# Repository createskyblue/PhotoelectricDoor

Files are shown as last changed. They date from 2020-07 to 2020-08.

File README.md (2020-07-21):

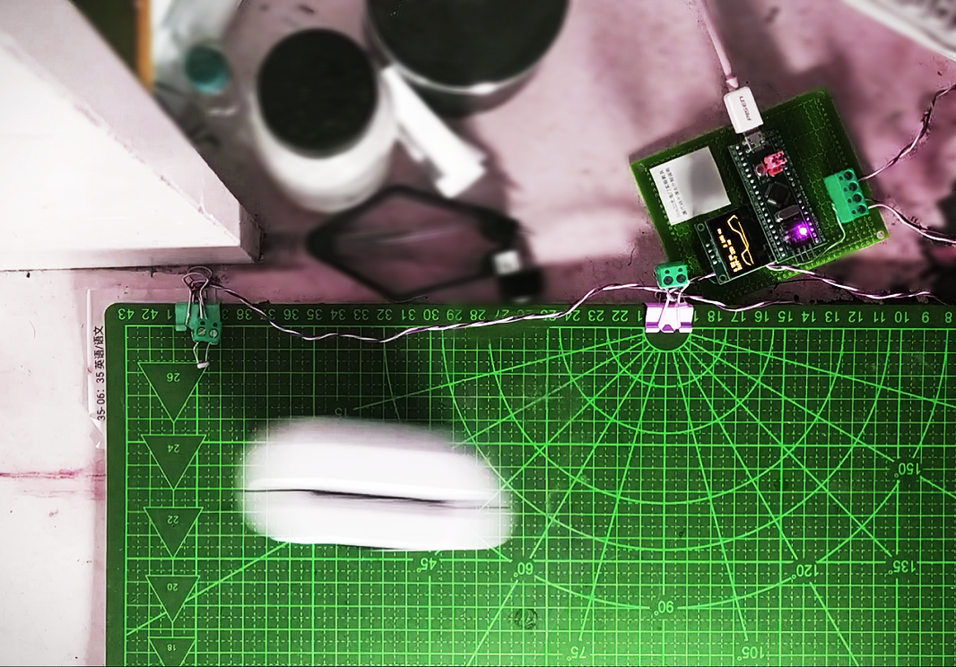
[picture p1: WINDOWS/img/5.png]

在这次实验，我们使用STM32单片机和由两个光敏电阻以及平行光源组组成的A和B两个光电门来计算运动物体的加速度，物体通过两个光敏电阻时会遮挡平行光，此时stm32单片机会记录下两个光敏电阻上的电位变化通过串口通讯把波形上传到计算机以待进一步分析，并且在STM32的OLED显示屏上显示出两个光敏电阻的遮光时间以及通过两个光敏电阻之间的时间差。
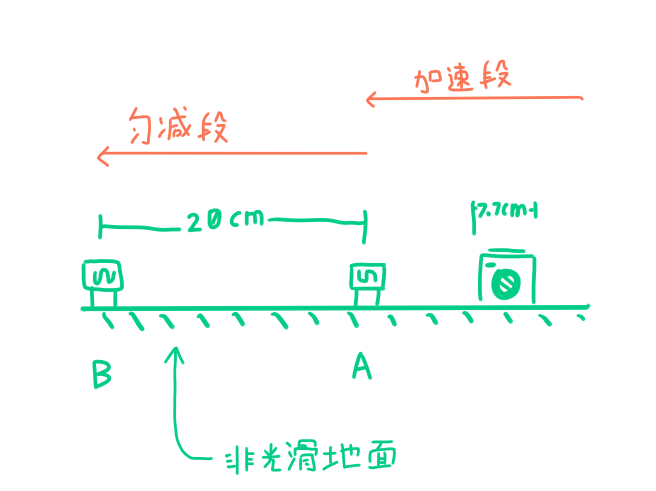
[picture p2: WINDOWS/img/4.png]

上图为为实验具体示意图，现在有一遮光长度为7.7CM的热敏打印机，我们对其进行加速直到打印机进入光电门A，计算机记录下第一个遮光时间t1，待热敏打印机通过光电门B时，计算机会记录下通过离开光电门A后直到进入光电门B的时间差t2，最后热敏打印机离开光电门B，计算机最后记录下第二个遮光时间t3。热敏打印机进入光电门A后受到摩檫力作匀减速运动，利用热敏打印机遮光长度7.7CM组合t1和t3可以计算出通过光电门A、B的速度V1和V2,最后利用时间差t3可以计算出热敏打印机作匀减运动的加速度！
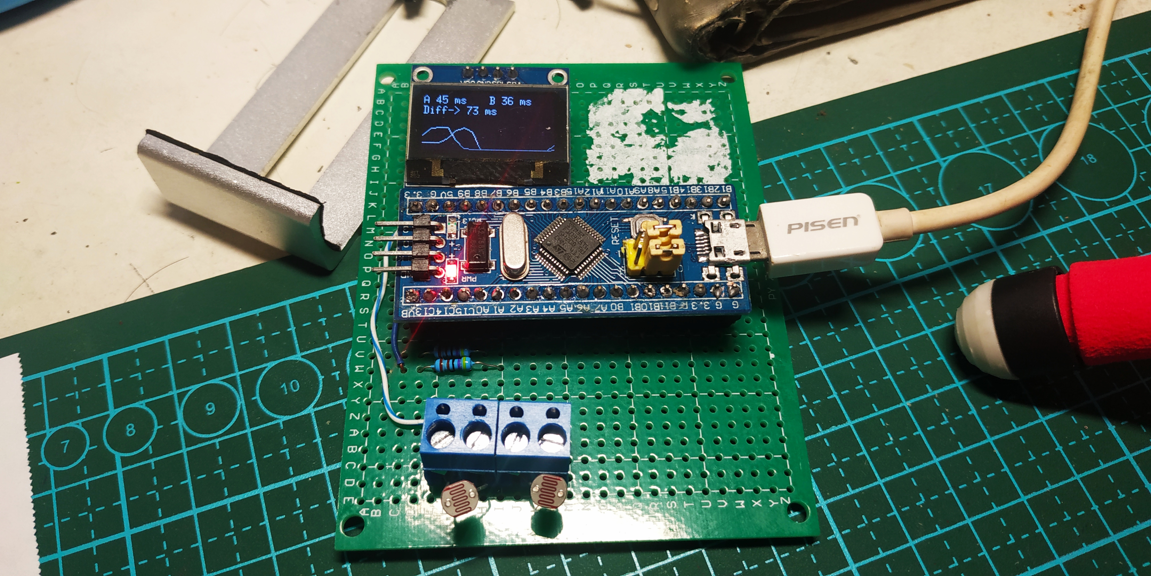
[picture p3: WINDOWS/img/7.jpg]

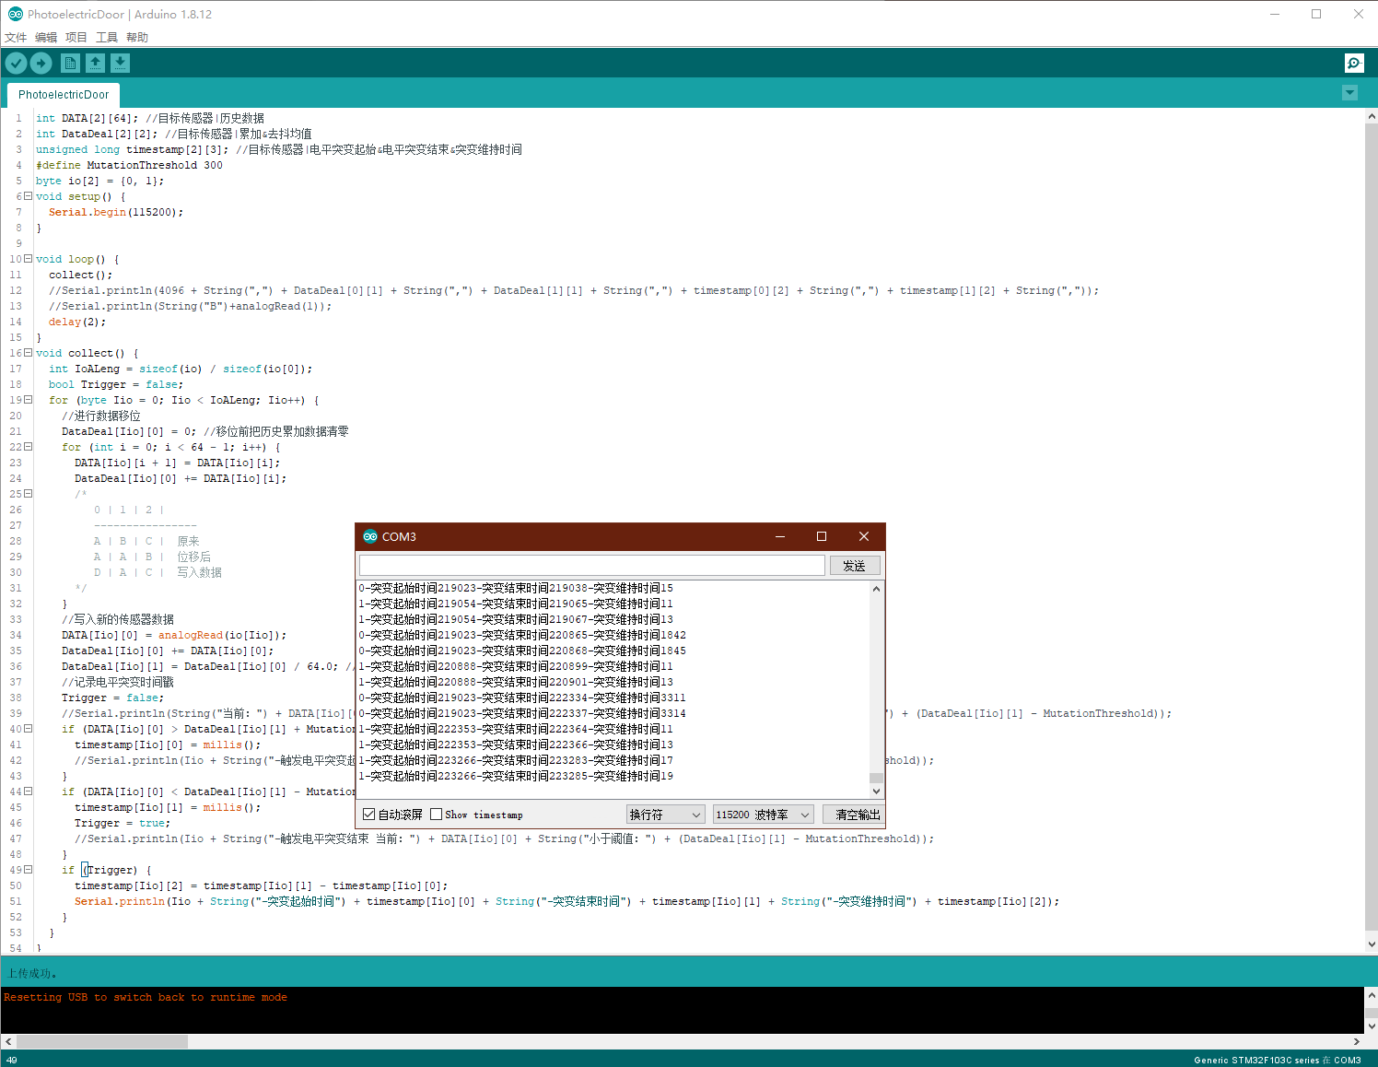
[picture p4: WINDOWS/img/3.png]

为了方便在大屏幕上进行演示，我还制作了上位机软件，根据STM32通过串口通讯上传的波形数据以及处理好的时间数据对加速度进行计算
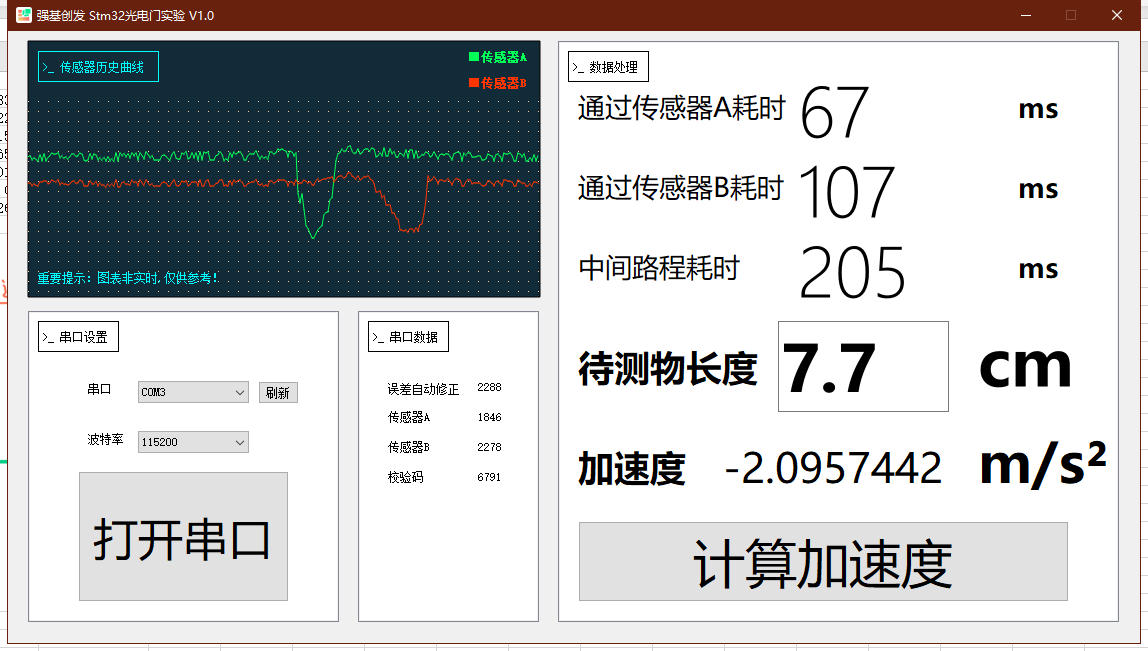
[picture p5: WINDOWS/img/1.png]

我们再重复进行多次实验，去除最高和最低的数据，得出这张加速度表
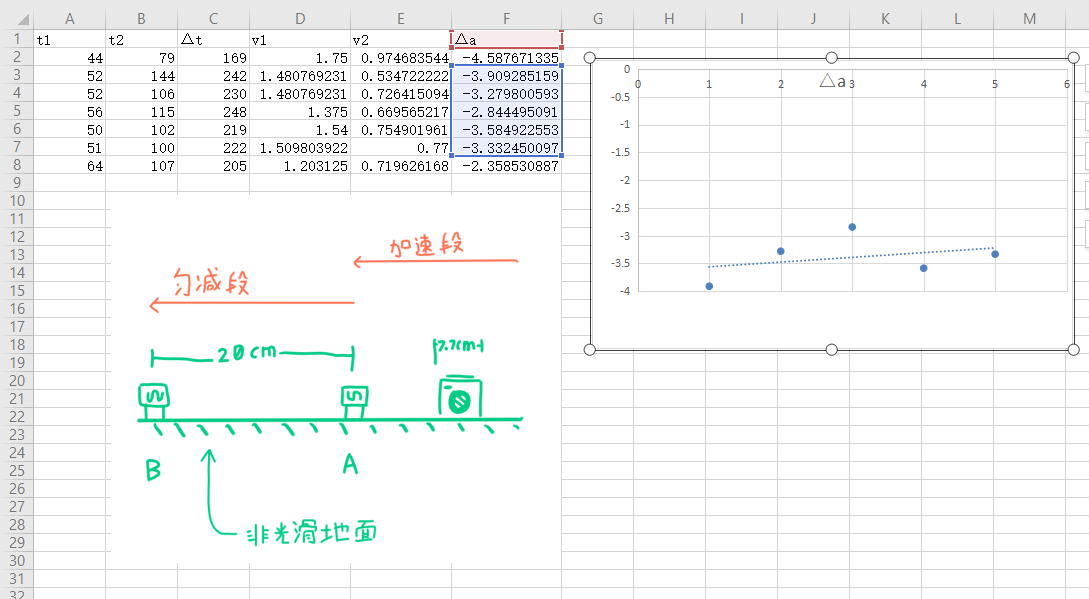
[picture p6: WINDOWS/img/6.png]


# 附录-1
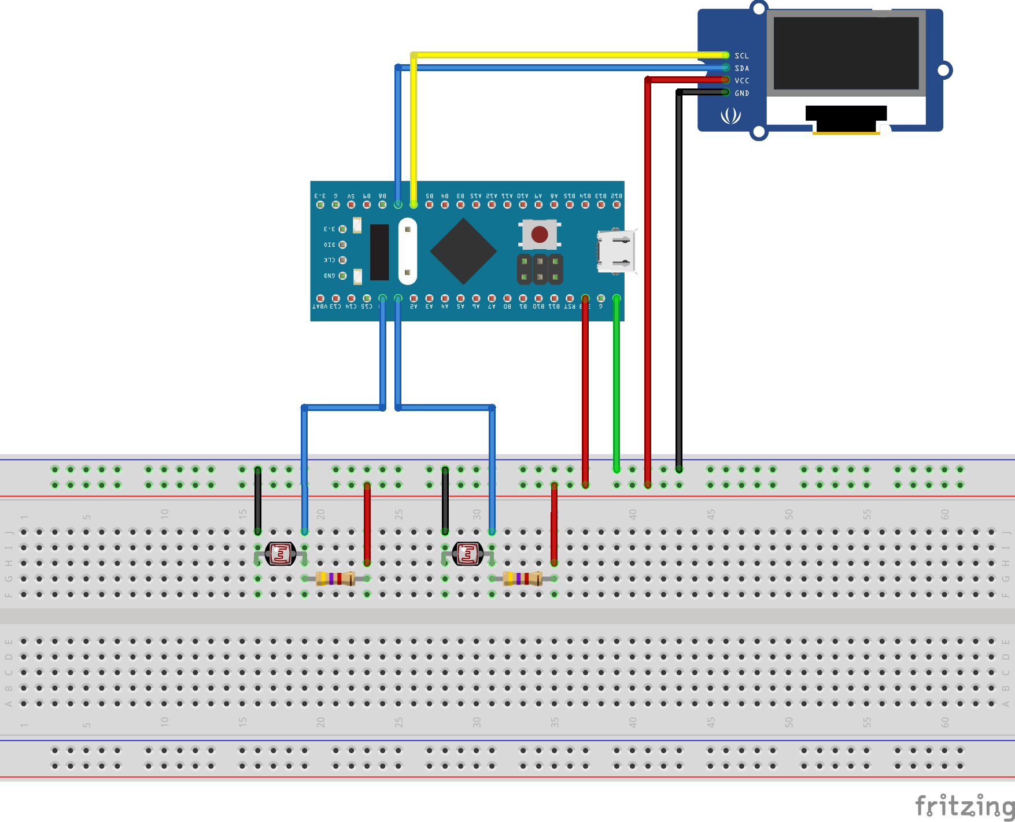
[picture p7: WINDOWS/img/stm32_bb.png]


###### 提示:STM32光电门程序后OLED会显示出启动信息，随后自动进行调光，此时请确保将光敏电阻置于实验环境下，当调光结束后OLED会显示两张启动画面中的一张譬如：

###### 则表明调光程序已自动完成，如果光照条件改变，请务必按下复位按钮重新调光！启动画面结束后随后进入操作界面，并且光电门时有顺序之分的，可以根据附带的接线图所示，光电门A连接到单片机的A0,光电门B连接到单片机的A1。进行试验时确保被测物先通过光电门A再通过光电门B，并且确保两光电门之间保持合适距离，确保收集到准确的实验数据！

# 附录-2
WINDOWS上位机软件所在目录
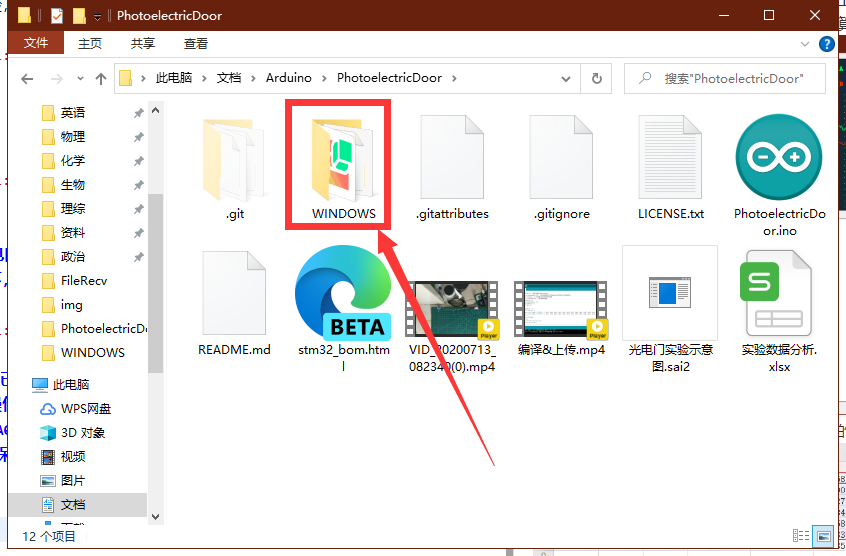
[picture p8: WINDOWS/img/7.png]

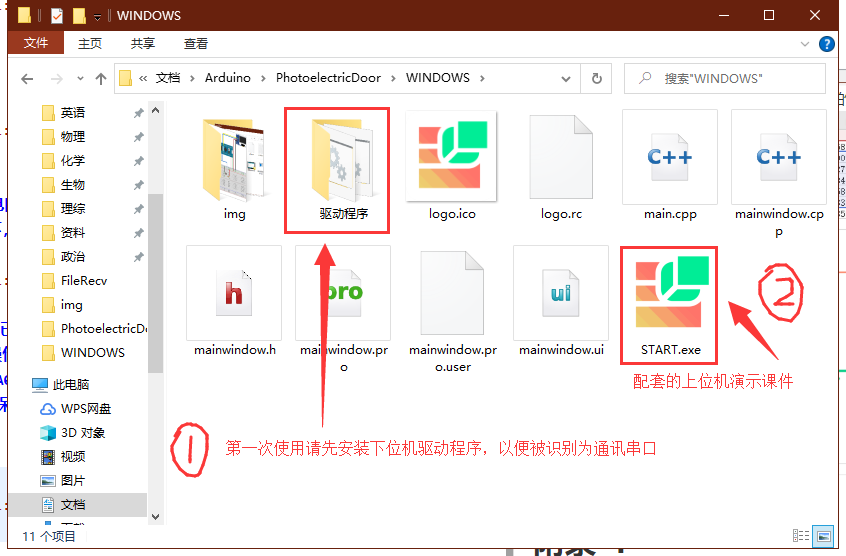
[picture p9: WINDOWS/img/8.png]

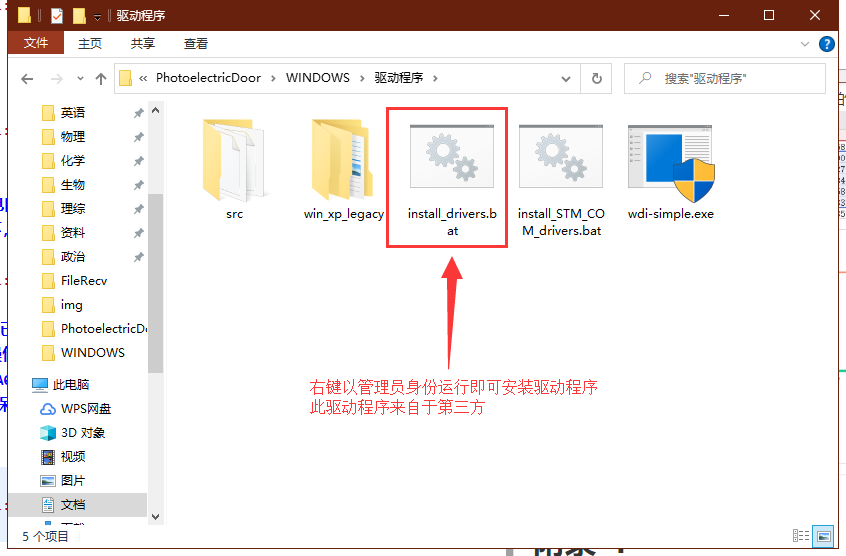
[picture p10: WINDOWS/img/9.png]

上位机软件操作
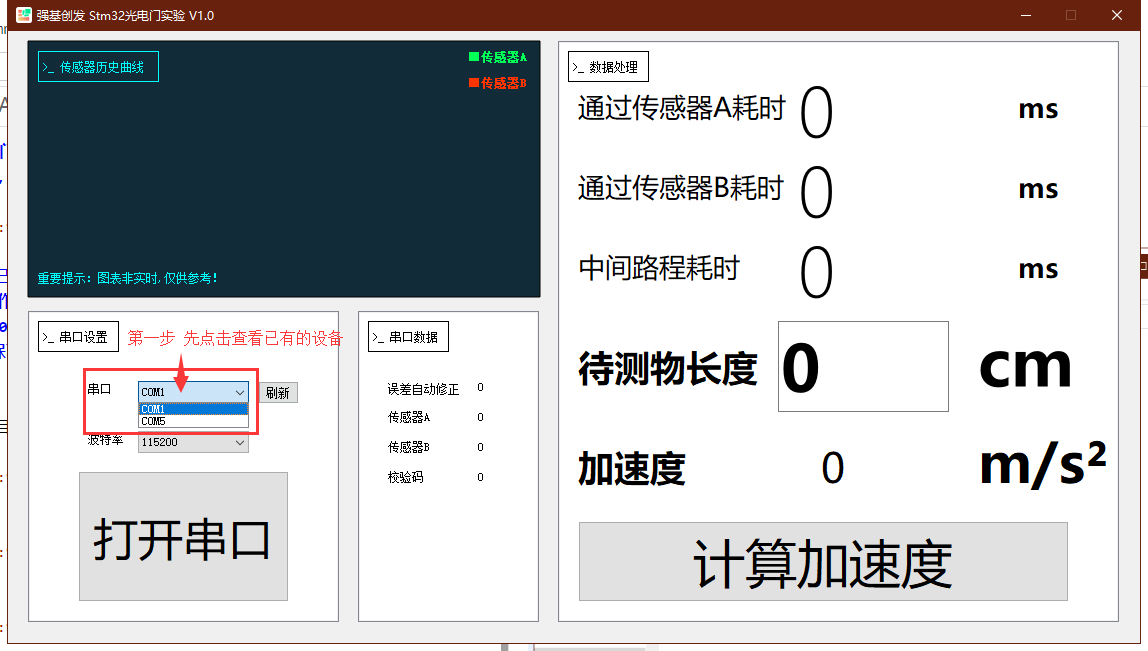
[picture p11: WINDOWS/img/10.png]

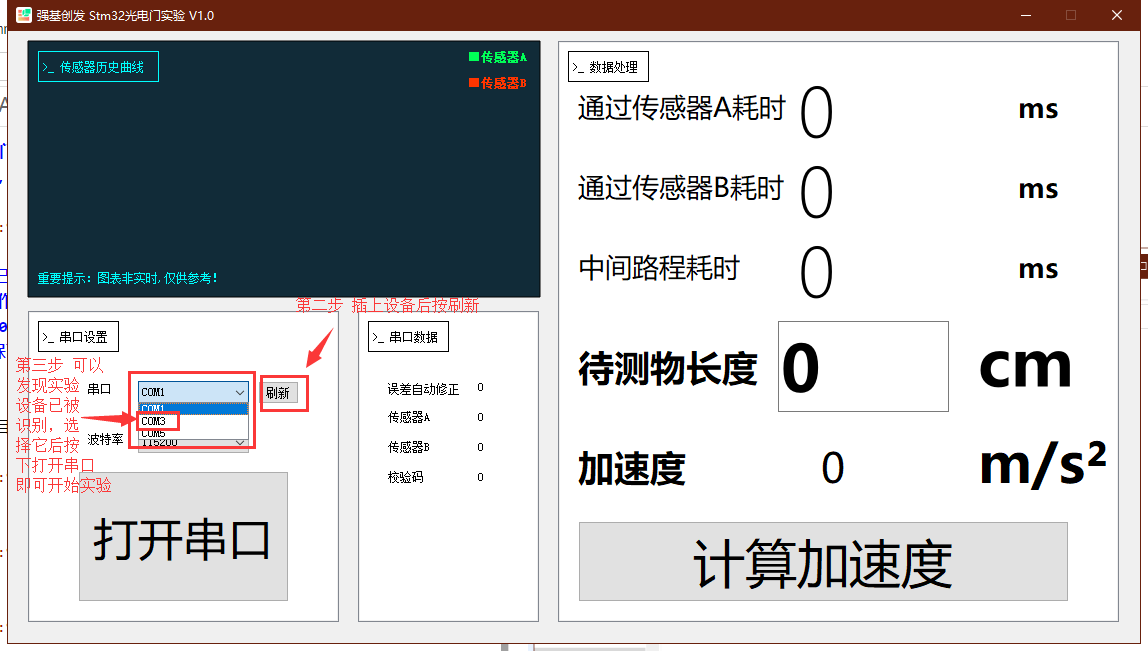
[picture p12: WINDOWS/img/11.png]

望各位老师使用愉快！若遇到问题可以发邮件到createskyblue@outlook.com

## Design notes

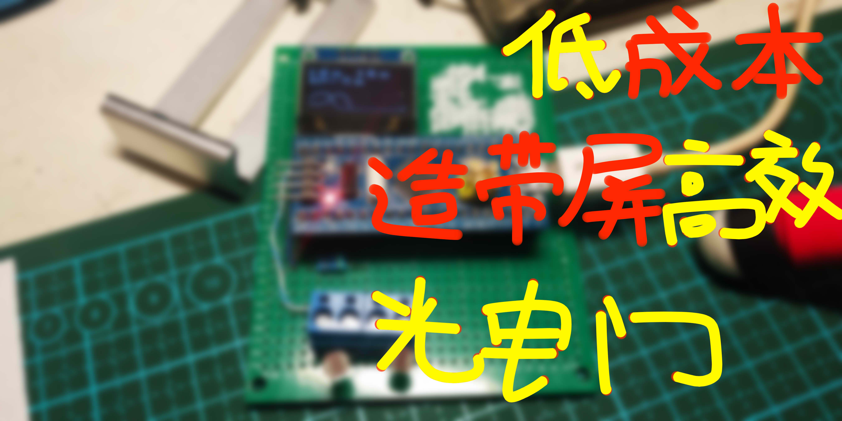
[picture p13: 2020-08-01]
WINDOWS/img/bilibili.jpg

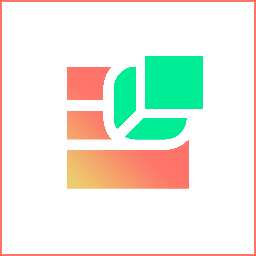
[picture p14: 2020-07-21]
WINDOWS/img/screen.png

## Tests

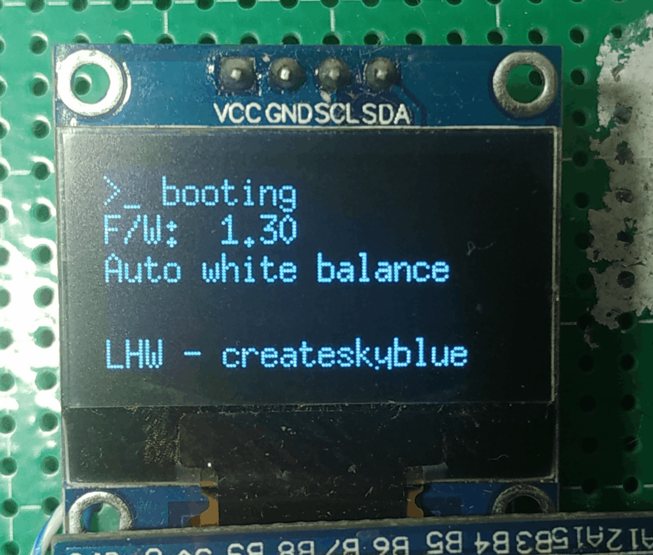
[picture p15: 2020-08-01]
WINDOWS/img/TestMode.gif

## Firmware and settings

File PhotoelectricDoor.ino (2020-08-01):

/*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
  光电门下位机程序版本:
  V2.0
*/
#include <U8g2lib.h>
//#include <SPI.h>
//U8G2_ST7565_JLX12864_F_4W_SW_SPI u8g2(U8G2_R0,19,20,14,22,21);
U8G2_SSD1306_128X64_NONAME_F_HW_I2C u8g2(U8G2_R0, /* clock=*/ PB6, /* data=*/ PB7, /* reset=*/ U8X8_PIN_NONE);
#define TmpDateMax 64
int DATA[2][TmpDateMax]; //目标传感器|历史数据
bool TriggerTimer = false;
bool GUIState = false;
bool State[2] = {1, 1}; //传感器状态
int grap[2][17]; //图形缓冲区
byte GrapX;
int DataDeal[2][2]; //目标传感器|累加&去抖均值
unsigned long timestamp[2][3]; //目标传感器|电平突变起始&电平突变结束&突变维持时间
unsigned long deltaT; //A,B传感器从起始到结束的时间差
unsigned long GrapSampling; //波形捕获时间戳
#define SysVersion 2.0
#define MutationThreshold 100
#define SamplingRate 10
#define PI 3.141592654
byte io[2] = {0, 1};
byte a = 0;
int LightIntensity = 0;
// width: 128, height: 64
const unsigned char Logo1[] PROGMEM = { 0xff, 0xbb, 0x56, 0x21, 0x00, 0x04, 0x81, 0xdb, 0xb6, 0xff, 0xff, 0xff, 0xff, 0xff, 0xff, 0xff, 0xff, 0xfb, 0xbb, 0x84, 0x24, 0x40, 0x48, 0xb6, 0x6d, 0xff, 0xff, 0xff, 0xff, 0xff, 0xff, 0xff, 0xff, 0xef, 0x56, 0x10, 0x80, 0x10, 0x80, 0x6a, 0xdb, 0xfe, 0x00, 0x00, 0x00, 0xfe, 0xff, 0xff, 0xff, 0xbf, 0x2b, 0x05, 0x21, 0x02, 0x08, 0xdd, 0xb6, 0x7f, 0xff, 0xff, 0xff, 0xfd, 0xff, 0xff, 0xff, 0xfb, 0x5b, 0x20, 0x08, 0x80, 0x00, 0xa8, 0x6d, 0x7f, 0xef, 0x7f, 0xc7, 0xfd, 0xff, 0xff, 0xff, 0x6f, 0x2b, 0x01, 0x00, 0x08, 0x48, 0xda, 0x5a, 0x7f, 0x83, 0x7d, 0xd7, 0xfd, 0xff, 0xff, 0xff, 0xdf, 0x15, 0x92, 0x84, 0x20, 0x02, 0x68, 0xb7, 0x7e, 0xef, 0x7e, 0xd7, 0xfd, 0xff, 0xff, 0xff, 0x2b, 0x55, 0x00, 0x10, 0x0a, 0x00, 0xd2, 0xaa, 0x7e, 0xc7, 0x3b, 0xd4, 0xfd, 0xff, 0xff, 0xff, 0x57, 0x8d, 0x24, 0xa5, 0x40, 0x91, 0x50, 0x55, 0x7f, 0xff, 0x7c, 0xd5, 0xfd, 0xff, 0xff, 0xff, 0x27, 0x09, 0x80, 0x54, 0x1b, 0x02, 0x20, 0xa9, 0x7f, 0xc7, 0x7b, 0xd5, 0xfd, 0xff, 0xff, 0xff, 0x57, 0xa5, 0x2a, 0xb5, 0x6a, 0x49, 0x44, 0xab, 0x7e, 0xc7, 0x7f, 0xd5, 0xfd, 0xff, 0xff, 0xff, 0x93, 0x0a, 0x44, 0xab, 0x95, 0x02, 0xa1, 0x76, 0x7f, 0xd7, 0x7b, 0xd5, 0xfd, 0xff, 0xff, 0xff, 0x57, 0x85, 0xa8, 0xda, 0xaa, 0x14, 0xc8, 0x8a, 0x7e, 0x81, 0xbc, 0xc5, 0xfd, 0xff, 0xff, 0xff, 0xab, 0x12, 0x55, 0xb7, 0x55, 0x89, 0x20, 0x55, 0x7f, 0xff, 0xff, 0xff, 0xfd, 0xff, 0xff, 0xff, 0xd7, 0x26, 0xda, 0xda, 0xae, 0x12, 0x44, 0x52, 0x7e, 0xff, 0xff, 0xff, 0xfd, 0xff, 0xff, 0xff, 0x5b, 0x85, 0xaa, 0xb7, 0x55, 0x55, 0x40, 0x95, 0x7e, 0xff, 0xff, 0xff, 0xfd, 0xff, 0xff, 0xff, 0xbf, 0x2a, 0x75, 0x7d, 0xab, 0x8a, 0x88, 0xa4, 0x7e, 0xbf, 0xbf, 0xf7, 0xfd, 0xff, 0xff, 0xff, 0xff, 0x83, 0xaa, 0xd7, 0xb6, 0x2a, 0xa2, 0x2a, 0x7f, 0xbf, 0xbf, 0xf7, 0xfd, 0xff, 0xff, 0xff, 0xff, 0x2a, 0x6d, 0xad, 0x55, 0x55, 0x80, 0xa4, 0x7e, 0xbf, 0x7f, 0xf7, 0xfd, 0xff, 0xff, 0xff, 0xff, 0x85, 0xda, 0x76, 0xad, 0x95, 0x48, 0x49, 0x7f, 0x07, 0xfe, 0xc1, 0xfd, 0xff, 0xff, 0xff, 0xff, 0x0a, 0x55, 0xaf, 0x6b, 0x55, 0x82, 0x2a, 0x7e, 0xb7, 0xbe, 0xd5, 0xfd, 0xff, 0xff, 0xff, 0xff, 0xa5, 0xb6, 0xdd, 0x5a, 0x95, 0x50, 0x52, 0x7f, 0x07, 0x7e, 0xc1, 0xfd, 0xff, 0xff, 0xff, 0x7f, 0x0b, 0xd5, 0xb6, 0x55, 0x55, 0x80, 0xa4, 0x7e, 0xbf, 0xff, 0xd5, 0xfd, 0xff, 0xff, 0xff, 0xdf, 0x2a, 0x6d, 0x6b, 0xbb, 0x2a, 0xaa, 0x4a, 0x7e, 0xbf, 0x7f, 0xd5, 0xfd, 0xff, 0xff, 0xff, 0x7f, 0x8b, 0xda, 0xde, 0xd6, 0x4a, 0x20, 0x91, 0x7e, 0xbf, 0x3f, 0xc1, 0xfd, 0xff, 0xff, 0xff, 0xf7, 0x1a, 0x25, 0x55, 0xb5, 0xaa, 0x44, 0x56, 0x7f, 0xff, 0xff, 0xff, 0xfd, 0xff, 0xff, 0xff, 0x7f, 0xab, 0x5a, 0xa9, 0x2d, 0x44, 0xa8, 0x52, 0x7e, 0xff, 0xff, 0xff, 0xfd, 0xff, 0xff, 0xff, 0xff, 0x16, 0xab, 0x6a, 0x4b, 0xa9, 0xa8, 0xea, 0x7e, 0xff, 0xff, 0xff, 0xfd, 0xff, 0xff, 0xff, 0x6f, 0x5d, 0x6d, 0x55, 0x95, 0x96, 0x5c, 0xf5, 0x7f, 0xff, 0xff, 0xff, 0xfd, 0xff, 0xff, 0xff, 0xff, 0x12, 0xd1, 0xaa, 0x52, 0x55, 0xf4, 0x62, 0x7f, 0x8f, 0xff, 0xff, 0xfd, 0xff, 0xff, 0xff, 0xbf, 0x0d, 0x20, 0xd4, 0xd5, 0xaa, 0xbe, 0xed, 0x7f, 0x8f, 0xff, 0xff, 0xfd, 0xff, 0xff, 0xff, 0x7b, 0x6b, 0x4d, 0xa1, 0x2a, 0xa9, 0x74, 0xf5, 0x7e, 0x8f, 0xff, 0xff, 0xfd, 0xff, 0xff, 0xff, 0xbf, 0x9a, 0x9a, 0x8a, 0x05, 0x00, 0x7a, 0xed, 0x7f, 0x8f, 0xff, 0xff, 0xfd, 0xff, 0xff, 0xff, 0xff, 0x96, 0x77, 0x1d, 0xd0, 0xb6, 0xb8, 0x6a, 0x7f, 0x8f, 0xff, 0xff, 0xfd, 0xff, 0xff, 0xff, 0xbf, 0xad, 0xaa, 0xaa, 0xa5, 0xaa, 0xbb, 0x95, 0x7e, 0x8f, 0xff, 0xff, 0xfd, 0xff, 0xff, 0xff, 0x7f, 0x2b, 0x6d, 0x87, 0xb1, 0x6a, 0x79, 0xab, 0x7e, 0x9f, 0xff, 0xff, 0xfd, 0xff, 0xff, 0xff, 0xbf, 0x1a, 0xdb, 0x6a, 0x63, 0xdb, 0x7e, 0x56, 0x7f, 0xff, 0xff, 0xff, 0xfd, 0xff, 0xff, 0xff, 0x77, 0x75, 0xb6, 0xc5, 0xaa, 0x56, 0xdf, 0xaa, 0x7e, 0x8f, 0xff, 0xff, 0xfd, 0xff, 0xff, 0xff, 0xdf, 0xee, 0xa9, 0x6a, 0x43, 0x49, 0xbf, 0x96, 0x7e, 0x8f, 0xff, 0xff, 0xfd, 0xff, 0xff, 0xff, 0xbf, 0x55, 0xab, 0xda, 0x5e, 0xf5, 0xde, 0x7a, 0x07, 0xff, 0xff, 0xff, 0xfd, 0xff, 0xff, 0xff, 0x5b, 0xfb, 0xb6, 0xea, 0x51, 0x4d, 0xfb, 0xff, 0xf7, 0xff, 0xff, 0xff, 0xfd, 0xff, 0xff, 0xff, 0xff, 0xae, 0xed, 0xb6, 0xd6, 0xda, 0xef, 0xef, 0xef, 0xff, 0xff, 0xff, 0xfd, 0xff, 0xff, 0xff, 0x9f, 0x75, 0x5b, 0xed, 0xad, 0xd5, 0xbe, 0x7d, 0xdf, 0xff, 0xff, 0xff, 0xfd, 0xff, 0xff, 0xff, 0x7b, 0xdb, 0xb6, 0x5b, 0xab, 0xb6, 0xfb, 0xef, 0xdf, 0xff, 0xff, 0xff, 0xfd, 0xff, 0xff, 0xff, 0xaf, 0xfe, 0x6d, 0xd5, 0xda, 0xed, 0x6f, 0x7d, 0xbf, 0xff, 0xff, 0xff, 0xfd, 0xff, 0xff, 0xff, 0xdf, 0x55, 0xdb, 0xae, 0x52, 0xb5, 0xda, 0xd7, 0x7f, 0x00, 0x00, 0x00, 0xfe, 0xff, 0xff, 0xff, 0xab, 0xee, 0xb6, 0xb5, 0xaa, 0xf6, 0xbd, 0x56, 0xfe, 0xff, 0xff, 0xff, 0xff, 0xff, 0xff, 0xff, 0xbf, 0xbd, 0xab, 0xae, 0xd5, 0x5a, 0x77, 0xa9, 0xfe, 0xff, 0xff, 0xff, 0xff, 0xff, 0xff, 0xff, 0xd7, 0xd6, 0x6e, 0x75, 0xad, 0xf6, 0x5b, 0x45, 0xff, 0xff, 0xff, 0xff, 0xff, 0xff, 0xff, 0xff, 0xbf, 0xfb, 0x5b, 0x45, 0xb5, 0x6d, 0x57, 0xfd, 0xff, 0xff, 0xff, 0xff, 0xff, 0xff, 0xff, 0xff, 0x6f, 0x57, 0x57, 0xb5, 0xa2, 0xfa, 0xea, 0xff, 0xff, 0xff, 0xff, 0xff, 0xff, 0xff, 0xff, 0xff, 0xef, 0xfe, 0x68, 0x6b, 0xad, 0xbe, 0xf7, 0xff, 0xff, 0xff, 0xff, 0xff, 0xff, 0xff, 0xff, 0xff, 0x5b, 0xd5, 0xaa, 0x56, 0x69, 0xed, 0xfd, 0xff, 0xff, 0xff, 0xff, 0xbf, 0xff, 0xf3, 0xff, 0xff, 0xdf, 0x6f, 0xd8, 0xaa, 0x56, 0xfd, 0xf3, 0xe3, 0xf1, 0x78, 0xfc, 0xbe, 0xfd, 0xef, 0xff, 0xff, 0xb7, 0x3a, 0xb5, 0xb6, 0xaa, 0xba, 0xef, 0xdd, 0x66, 0xb7, 0xf9, 0xbd, 0xfd, 0xff, 0xff, 0xff, 0xef, 0xb7, 0xa8, 0x6d, 0xb5, 0xfc, 0xf7, 0xdd, 0x66, 0xb7, 0xf9, 0x3d, 0x70, 0x00, 0xfc, 0xff, 0xb7, 0x2e, 0x5a, 0x55, 0x4b, 0xf2, 0xff, 0xdd, 0x66, 0xb7, 0xf9, 0xdb, 0x7d, 0x7e, 0xff, 0xff, 0x6f, 0x4b, 0x74, 0xab, 0x5a, 0xf9, 0xff, 0xdf, 0xe6, 0xb7, 0x79, 0xdf, 0xfd, 0xbe, 0xff, 0xff, 0xb7, 0x9f, 0xaa, 0xaa, 0x92, 0xb2, 0xef, 0xdf, 0xea, 0xb7, 0xfa, 0x7e, 0xf0, 0xdd, 0xff, 0xff, 0xef, 0x3b, 0xa8, 0x55, 0x55, 0xea, 0xff, 0xef, 0xec, 0x3b, 0xfb, 0xf6, 0xff, 0xeb, 0xff, 0xff, 0xfb, 0xae, 0x52, 0x5b, 0xa5, 0xf0, 0xee, 0xf7, 0xec, 0x3d, 0xfb, 0x3b, 0xf0, 0xf3, 0xff, 0xff, 0xbf, 0x5b, 0xb4, 0x56, 0x2d, 0xab, 0xff, 0xfb, 0xec, 0x3e, 0xfb, 0xbd, 0xf7, 0xed, 0xff, 0xff, 0xf7, 0x3f, 0xc1, 0x6a, 0xd5, 0xe4, 0xff, 0xfd, 0x6c, 0x3f, 0xfb, 0xbe, 0x77, 0x9e, 0xff, 0xff, 0xdb, 0xaa, 0xa4, 0x5a, 0xab, 0xd2, 0xf7, 0xc1, 0x71, 0x70, 0xfc, 0x3e, 0xb0, 0x7f, 0xfe };
const unsigned char Logo2[] PROGMEM = { 0xff, 0xff, 0xff, 0xff, 0xff, 0xff, 0xff, 0xff, 0xff, 0xff, 0xff, 0xff, 0xff, 0xff, 0xff, 0xff, 0x07, 0x00, 0x00, 0x00, 0x00, 0x00, 0x00, 0x00, 0x00, 0x00, 0x00, 0x00, 0x00, 0x00, 0x00, 0xe0, 0xfb, 0xff, 0xff, 0xff, 0xff, 0xff, 0xff, 0xff, 0xff, 0xff, 0xff, 0xff, 0xff, 0xff, 0xff, 0xdf, 0x9d, 0xff, 0xff, 0xff, 0xff, 0xff, 0xff, 0xff, 0xff, 0xff, 0xff, 0xff, 0xff, 0xff, 0xff, 0xbf, 0x9d, 0xff, 0xff, 0xff, 0xff, 0xff, 0xff, 0xff, 0xff, 0xff, 0xff, 0xff, 0xff, 0xff, 0xcf, 0xb3, 0xfd, 0xff, 0xff, 0xff, 0xff, 0xff, 0xff, 0xff, 0xff, 0xff, 0xff, 0xff, 0xff, 0xff, 0x9f, 0xb9, 0x9d, 0xff, 0xff, 0xff, 0xff, 0xff, 0xff, 0xff, 0xff, 0xff, 0xff, 0xff, 0xff, 0xff, 0x3f, 0xbc, 0x9d, 0xff, 0xff, 0xff, 0xff, 0xff, 0xff, 0xff, 0xff, 0xff, 0xff, 0xff, 0xff, 0xff, 0x7f, 0xbe, 0x9d, 0xff, 0xff, 0xff, 0xff, 0xff, 0xff, 0xff, 0xff, 0xff, 0xff, 0xff, 0xff, 0xff, 0x3f, 0xbc, 0x9d, 0xff, 0xff, 0xff, 0xff, 0xff, 0xff, 0xff, 0xff, 0xff, 0xff, 0xff, 0xff, 0xff, 0x9f, 0xb9, 0x9d, 0xff, 0xff, 0xff, 0xff, 0xff, 0xff, 0xff, 0xff, 0xff, 0xff, 0xff, 0xff, 0xff, 0xcf, 0xb3, 0xfd, 0xff, 0xff, 0xff, 0xff, 0xff, 0xff, 0xff, 0xff, 0xff, 0xff, 0xff, 0xff, 0xff, 0xff, 0xbf, 0x01, 0x00, 0x00, 0x00, 0x00, 0x00, 0x00, 0x00, 0x00, 0x00, 0x00, 0x00, 0x00, 0x00, 0x00, 0x80, 0xfd, 0xff, 0xff, 0xff, 0xff, 0xff, 0xff, 0xff, 0xff, 0xff, 0xff, 0xff, 0xff, 0xff, 0xff, 0xbf, 0xfd, 0xff, 0xff, 0xff, 0xff, 0xf9, 0x0f, 0x00, 0xfe, 0xf3, 0xe7, 0xe1, 0x3f, 0xff, 0xe4, 0xbc, 0xfd, 0xff, 0xff, 0xff, 0xff, 0xfc, 0xcf, 0x7f, 0x06, 0xe7, 0xe7, 0xc9, 0x3f, 0xff, 0x49, 0xbe, 0xfd, 0xff, 0xff, 0xff, 0x1f, 0x00, 0x0c, 0x00, 0x26, 0xff, 0x07, 0xc9, 0x3f, 0xff, 0x3f, 0xbf, 0xfd, 0xff, 0xff, 0xff, 0x9f, 0xff, 0xcc, 0x79, 0x26, 0x00, 0xe7, 0xf9, 0x3f, 0x3f, 0x00, 0xb0, 0xfd, 0xff, 0xff, 0xff, 0x9f, 0xff, 0xcc, 0x79, 0x86, 0xf9, 0xe7, 0x81, 0x3f, 0x3f, 0xff, 0xb3, 0xfd, 0xff, 0xff, 0xff, 0x9f, 0x80, 0x4c, 0x40, 0x86, 0xf9, 0x67, 0xf8, 0x00, 0x00, 0xff, 0xb3, 0xfd, 0xff, 0xff, 0xff, 0x9f, 0x9c, 0xcc, 0x79, 0x26, 0x81, 0x01, 0xc9, 0x3f, 0xff, 0x00, 0xbe, 0xfd, 0xff, 0xff, 0xff, 0x9f, 0x9c, 0xcc, 0x61, 0x26, 0x99, 0x39, 0xc9, 0x3f, 0xff, 0x3f, 0xbf, 0xfd, 0xff, 0xff, 0xff, 0x9f, 0x9c, 0xcc, 0x49, 0x26, 0x99, 0x39, 0xe1, 0x3f, 0xff, 0x8f, 0xbf, 0xfd, 0xff, 0xff, 0xff, 0x9f, 0x80, 0x0c, 0x00, 0x26, 0x99, 0x39, 0xe1, 0x3f, 0x3f, 0x00, 0xb0, 0xfd, 0xff, 0xff, 0xff, 0x9f, 0xff, 0xcc, 0x7f, 0x86, 0x99, 0x39, 0x93, 0x3f, 0xff, 0xcf, 0xbf, 0xfd, 0xff, 0xff, 0xff, 0x9f, 0xff, 0xcc, 0x7f, 0xe6, 0x9c, 0x01, 0x81, 0x3f, 0xff, 0xcf, 0xbf, 0xfd, 0xff, 0xff, 0xff, 0x9f, 0xff, 0x0c, 0x00, 0xe6, 0x9c, 0x39, 0x8c, 0x3f, 0xff, 0xcf, 0xbf, 0xfd, 0xff, 0xff, 0xff, 0x9f, 0x3f, 0xcc, 0x7f, 0x66, 0xc6, 0x7f, 0x9e, 0x01, 0xe0, 0xc3, 0xbf, 0xfd, 0xff, 0xff, 0xff, 0xff, 0xff, 0xff, 0xff, 0xff, 0xff, 0xff, 0xff, 0xff, 0xff, 0xff, 0xbf, 0xfd, 0xff, 0xff, 0xff, 0xff, 0xff, 0xff, 0xff, 0xff, 0xff, 0xff, 0xff, 0xff, 0xff, 0xff, 0xbf, 0xfd, 0xff, 0xff, 0xfc, 0x7f, 0xce, 0x9f, 0xcf, 0xff, 0xf9, 0x7f, 0xfe, 0x3f, 0xe7, 0xff, 0xbf, 0x7d, 0x00, 0xf8, 0xfc, 0x7f, 0xce, 0x3f, 0xcf, 0xff, 0xf0, 0xff, 0xfc, 0x67, 0x66, 0x10, 0xb8, 0xfd, 0xff, 0xf9, 0xfc, 0x7f, 0x02, 0xfc, 0xcf, 0x7f, 0xe6, 0x07, 0x80, 0x67, 0xe6, 0x93, 0xb9, 0xfd, 0xff, 0x19, 0x00, 0x78, 0xcc, 0x0c, 0xce, 0x3f, 0xcf, 0xff, 0xfc, 0xcf, 0xf3, 0x93, 0xb9, 0xfd, 0xf9, 0xf9, 0x84, 0x19, 0xc8, 0x7c, 0xce, 0x9f, 0x9f, 0xff, 0xfc, 0xcf, 0x73, 0x10, 0xb8, 0xfd, 0xf3, 0xf9, 0x84, 0x19, 0xce, 0x3c, 0x01, 0x06, 0x00, 0xfe, 0xfc, 0x9f, 0x79, 0x7e, 0xbe, 0xfd, 0x33, 0xf9, 0x84, 0x19, 0xce, 0x3c, 0xcf, 0xff, 0xff, 0xff, 0xfc, 0x9f, 0x79, 0x0e, 0xb0, 0xfd, 0x8f, 0xf9, 0x84, 0x79, 0x00, 0x18, 0xce, 0xff, 0xff, 0x0f, 0xc0, 0x3f, 0x7c, 0x4e, 0xb2, 0xfd, 0xe3, 0x79, 0x86, 0x79, 0x0e, 0x0f, 0xcc, 0x0f, 0x00, 0xff, 0xfc, 0x7f, 0x7e, 0x40, 0xb2, 0xfd, 0xf8, 0x79, 0x86, 0x79, 0x0e, 0x3f, 0xcf, 0xff, 0xfc, 0xff, 0xfc, 0x3f, 0xfc, 0x03, 0xb0, 0x3d, 0xfe, 0x79, 0x86, 0x79, 0x66, 0x3e, 0xcf, 0x7f, 0xe6, 0xff, 0xfc, 0x9f, 0xf9, 0x73, 0xbe, 0xfd, 0xff, 0x39, 0x07, 0x78, 0x66, 0x3e, 0xcf, 0x3f, 0xcf, 0xff, 0xfc, 0xcf, 0xf3, 0x73, 0xb2, 0xfd, 0xff, 0x3c, 0x87, 0x79, 0xf2, 0x3c, 0xcf, 0x1f, 0x80, 0xff, 0xfc, 0xe7, 0xe7, 0x03, 0xa0, 0xfd, 0x3f, 0x9e, 0xf1, 0x7f, 0xf8, 0x39, 0x00, 0xfc, 0x9f, 0x03, 0x00, 0xf1, 0x8f, 0xf8, 0xa7, 0xfd, 0xff, 0xff, 0xff, 0xff, 0xff, 0xff, 0xff, 0xff, 0xff, 0xff, 0xff, 0xff, 0xff, 0xff, 0xbf, 0xfd, 0xff, 0xff, 0xff, 0xff, 0xff, 0xff, 0xff, 0xff, 0xff, 0xff, 0xff, 0xff, 0xff, 0xff, 0xbf, 0x1d, 0x00, 0xfc, 0x9f, 0x3f, 0xff, 0xff, 0xff, 0xff, 0xff, 0xff, 0xff, 0xff, 0xff, 0xff, 0xbf, 0x9d, 0xff, 0xfc, 0x9f, 0x7f, 0x06, 0xfe, 0xf1, 0xff, 0xff, 0xff, 0xff, 0xff, 0xff, 0xff, 0xbf, 0x1d, 0x00, 0x1c, 0x00, 0x7c, 0x66, 0xfe, 0xf1, 0xff, 0xff, 0xff, 0xff, 0xff, 0xff, 0xff, 0xbf, 0x9d, 0xf3, 0xfc, 0x9c, 0xfc, 0x67, 0xfe, 0xf1, 0xff, 0xff, 0xff, 0xff, 0xff, 0xff, 0xff, 0xbf, 0x9d, 0xf3, 0x7c, 0x00, 0xf8, 0x67, 0xfe, 0xf1, 0xff, 0xff, 0xff, 0xff, 0xff, 0xff, 0xff, 0xbf, 0x9d, 0x80, 0x7c, 0x9e, 0x1c, 0xf2, 0xf8, 0xf1, 0xff, 0xff, 0xff, 0xff, 0xff, 0xff, 0xff, 0xbf, 0x9d, 0xf3, 0x3c, 0x03, 0x7c, 0xf8, 0xff, 0xf1, 0xff, 0xff, 0xff, 0xff, 0xff, 0xff, 0xff, 0xbf, 0x9d, 0xc3, 0x3c, 0x9c, 0x7f, 0x02, 0xfc, 0xf1, 0xff, 0xff, 0xff, 0xff, 0xff, 0xff, 0xff, 0xbf, 0x9d, 0x93, 0xfc, 0x00, 0x7c, 0xe6, 0xfc, 0xf1, 0xff, 0xff, 0xff, 0xff, 0xff, 0xff, 0xff, 0xbf, 0x1d, 0x00, 0x3c, 0x9c, 0x7f, 0x66, 0xfe, 0xf1, 0xff, 0xff, 0xff, 0xff, 0xff, 0xff, 0xff, 0xbf, 0x9d, 0xff, 0x7c, 0x00, 0x78, 0x08, 0xff, 0xff, 0xff, 0xff, 0xff, 0xff, 0xff, 0xff, 0xff, 0xbf, 0x9d, 0xff, 0x7c, 0x9e, 0x7f, 0x9c, 0xff, 0xf1, 0xff, 0xff, 0xff, 0xff, 0xff, 0xff, 0xff, 0xbf, 0x1d, 0x00, 0x3c, 0x9c, 0x7f, 0x06, 0xfe, 0xf1, 0xff, 0xff, 0xff, 0xff, 0xff, 0xff, 0xff, 0xbf, 0x9d, 0xff, 0x9c, 0x01, 0xf8, 0xf1, 0xf8, 0xf1, 0xff, 0xff, 0xff, 0xff, 0xff, 0xff, 0xff, 0xbf, 0xfd, 0xff, 0xff, 0xff, 0xff, 0xff, 0xff, 0xff, 0xff, 0xff, 0xff, 0xff, 0xff, 0xff, 0xff, 0xbf, 0xfb, 0xff, 0xff, 0xff, 0xff, 0xff, 0xff, 0xff, 0xff, 0xff, 0xff, 0xff, 0xff, 0xff, 0xff, 0xdf, 0x07, 0x00, 0x00, 0x00, 0x00, 0x00, 0x00, 0x00, 0x00, 0x00, 0x00, 0x00, 0x00, 0x00, 0x00, 0xe0, 0xff, 0xff, 0xff, 0xff, 0xff, 0xff, 0xff, 0xff, 0xff, 0xff, 0xff, 0xff, 0xff, 0xff, 0xff, 0xff };
//60x60
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
void loop() {
  collect();
  MakeGrap();
  SerialOutPut();
  //if (State[0]&State[1] & timestamp[1][1] > timestamp[0][0]) GUI(); //捕捉信号时限制刷新画面以保证采样性能  //因为动画带来不必要的刷新过于消耗资源，所以禁用了
}
//启动动画
void BootAnimation() {
  byte BAPointObj_PD_X = 48;
  //动画第一阶段：光敏电阻
  for (BAPointObj_PD_X; BAPointObj_PD_X > 16; BAPointObj_PD_X--) {
    u8g2.clearBuffer();
    Draw_BAPointObj_BJ();
    Draw_BAPointObj_PD(BAPointObj_PD_X, map(BAPointObj_PD_X, 48, 16, 0, 12));
    u8g2.sendBuffer();
  }
  //第二阶段：标题->sin(x)
  for (float x = 0; x < 2 * PI; x += 0.1) {
    u8g2.clearBuffer();
    Draw_BAPointObj_BJ();
    u8g2.setDrawColor(0);
    u8g2.drawXBMP(byte(32 + x * 5.09), byte(20 + sin(x) * 16), 51, 27, BANote); //浮动的标题
    Draw_BAPointObj_PD(16, 12);
    u8g2.sendBuffer();
  }
  //最后阶段：首创者信息
  u8g2.drawBox(0, 51, 128, 14 );
  u8g2.setDrawColor(1);
  u8g2.setCursor(4, 62);
  u8g2.print("LHW - createskyblue");
}
void Draw_BAPointObj_PD(byte x, byte y) {
  u8g2.drawXBMP(x, y, 32, 32, photoresistance);
  u8g2.drawLine(x + 3, y + 32, x + 3, y + 60);
  u8g2.drawLine(x + 27, y + 32, x + 27, y + 60);
}
void Draw_BAPointObj_BJ() {
  u8g2.setDrawColor(1);
  u8g2.drawBox(0, 0, 128, 64 );
  u8g2.setDrawColor(0);
}
void SerialOutPut() {
  int CheckCode = 4096 + DataDeal[0][1] + DataDeal[1][1] - LightIntensity + timestamp[0][2] + timestamp[1][2] + deltaT;
  Serial.println((4096 - LightIntensity) + String(",") + DataDeal[0][1]  + String(",") + DataDeal[1][1]  + String(",") + CheckCode + String(",") + timestamp[0][2] + String(",") + timestamp[1][2] + String(",") + deltaT + String(","));
}
void collect() {
  int IoALeng = sizeof(io) / sizeof(io[0]);
  bool Trigger = false;
  for (byte Iio = 0; Iio < IoALeng; Iio++) {
    //进行数据移位
    DataDeal[Iio][0] = 0; //移位前把历史累加数据清零
    for (int i = 0; i < TmpDateMax - 1; i++) {
      DATA[Iio][i] = DATA[Iio][i + 1];
      DataDeal[Iio][0] += DATA[Iio][i + 1];
    }
    //写入新的传感器数据
    //DATA[Iio][7] = analogRead(io[Iio]) - LightIntensity;
    DATA[Iio][TmpDateMax - 1] = analogRead(io[Iio]);
    DataDeal[Iio][0] += DATA[Iio][TmpDateMax - 1];
    DataDeal[Iio][1] = DataDeal[Iio][0] / float(TmpDateMax); //计算均值
    //记录电平突变时间戳
    Trigger = false;
    //限定幅度均值动态调整，效率高 v1.2
    // Serial.println(Iio+String("->目前：") + DATA[Iio][TmpDateMax-1] + String("大于阈值：") + (1.2 * DataDeal[Iio][1])+String("小于阈值：") + (0.8 * DataDeal[Iio][1]));
    if (DATA[Iio][TmpDateMax - 1] > (1.05 * DataDeal[Iio][1]) && State[Iio] == 1) {
      // Serial.println(Iio+String("->####"));
      timestamp[Iio][0] = millis();
      State[Iio] = 0;
      //Serial.println(timestamp[1][0]+String(" , ")+timestamp[1][1]);
      //Serial.println(Iio + String("-触发电平突变起始 当前：") + DATA[Iio][0] + String("大于阈值：") + (DataDeal[Iio][1] + MutationThreshold));
    }
    if (DATA[Iio][TmpDateMax - 1] < (0.95 * DataDeal[Iio][1]) && millis() > timestamp[Iio][0] && State[Iio] == 0) {
      // Serial.println(Iio+String("->#############"));
      timestamp[Iio][1] = millis();
      Trigger = true;
      State[Iio] = 1;
      //Serial.println(timestamp[1][0]+String(" , ")+timestamp[1][1]);
    }
    if (Trigger) {
      timestamp[Iio][2] = timestamp[Iio][1] - timestamp[Iio][0];
      if (TriggerTimer) {
        if (timestamp[1][0] > timestamp[0][1]) {
          deltaT = timestamp[1][0] - timestamp[0][1];
          GUIState = true;
          GUI();
        } else {
          GUIState = false;
          GUI();
        }
        //Serial.println(Iio + String("-突变起始时间") + timestamp[Iio][0] + String("-突变结束时间") + timestamp[Iio][1] + String("-突变维持时间") + timestamp[Iio][2]);
        Trigger = false;
      }
      if (State[0] = 1) TriggerTimer = !TriggerTimer;
    }
  }
}

void TestMode() {
  u8g2.clearBuffer();
  u8g2.drawXBMP(0, 0, 128, 64, TestModeNote);
  for (byte i; i < 128; i += 1) {
    //delay(6);
    u8g2.setDrawColor(0);
    u8g2.drawBox(0, 60, i, 4);
    u8g2.sendBuffer();
  }
  u8g2.setDrawColor(1);
  if (analogRead(0) > LightIntensity * 1.4 | analogRead(1) > LightIntensity * 1.4) {
    GUIState = true;
    while (1) {
      u8g2.clearBuffer();
      //u8g2.drawBox(0, 0, 128, 64);
      u8g2.drawXBMP(0, 7, 128, 14, TestModeNote);
      grap[0][GrapX] = map(analogRead(io[0]), 0, 4095, 0, 33);
      grap[1][GrapX] = map(analogRead(io[1]), 0, 4095, 0, 33);
      GrapX++;
      if (GrapX >= 17) GrapX = 0;
      DrawWave();//绘制波形
      u8g2.drawLine(GrapX * 8, 28, GrapX * 8, 64); //扫描线
      u8g2.sendBuffer();
      delay(15);
    }
  }
}

void MakeGrap() {
  if (timestamp[1][1] < timestamp[0][0]) { //只捕捉实验范围内的信号，节省资源
    if (!State[0] && State[1] && GrapX > 8) {
      GrapX = 0;
      for (byte i = 0; i < 17; i++) {
        grap[0][i] = 0;
        grap[1][i] = 0;
      }
    }
    if (GrapX < 17 && GrapSampling + SamplingRate < millis()) {
      grap[0][GrapX] = map(DataDeal[0][1], 0, 4095, 0, 33);
      grap[1][GrapX] = map(DataDeal[1][1], 0, 4095 , 0, 33);
      GrapX++;
      GrapSampling = millis();
    }
  }
}
void GUI() {
  u8g2.clearBuffer();
  u8g2.setCursor(4, 12);
  if (GUIState) u8g2.drawBox(0, 0, 128, 26);
  u8g2.print("A ");
  u8g2.print(timestamp[0][2]);
  u8g2.print(" ms");
  u8g2.setCursor(64, 12);
  u8g2.print("B ");
  u8g2.print(timestamp[1][2]);
  u8g2.print(" ms");

  DrawWave();//绘制波形

  //显示时间差
  u8g2.setCursor(4, 24);
  if (GUIState) {
    u8g2.print("Diff-> ");
    u8g2.print(deltaT);
    u8g2.print(" ms");
  } else {
    if ((millis() / 1000) % 2|1) u8g2.drawBox(0, 14, 128, 12); //'|1'因为动画带来不必要的刷新过于消耗资源，所以禁用了
    u8g2.print("#Unrecognized Wave!");
    u8g2.drawXBMP(23, 36, 82, 16, Error1);
  }


  u8g2.sendBuffer();
}
void DrawWave() {
  //绘制图形框
  u8g2.drawFrame(0, 28, 128, 36);
  //绘制计数点，看起来更有逼格
  for (byte y = 29; y < 64; y += 8)
    for (byte x = 1; x < 128; x += 8)
      u8g2.drawPixel(x, y);
  //绘制实时曲线
  if (GUIState) for (int i = 0; i < 16; i++) {
      u8g2.drawLine(8 * i, 63 - grap[0][i], 8 * (i + 1), 63 - grap[0][i + 1]);
      u8g2.drawLine(8 * i, 63 - grap[1][i], 8 * (i + 1), 63 - grap[1][i + 1]);
    }
}

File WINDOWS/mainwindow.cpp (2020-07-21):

#include "mainwindow.h"
#include "ui_mainwindow.h"
#include <QDebug>
#include <QPainter>
#include <QVector> //顺序容器
#include <QTextEdit>
#include <Windows.h>
#include <QDesktopServices> //用于打开超链接
#define ReceiveDataLeng 256
#define Graphics_Frame_X 20
#define Graphics_Frame_Y 10
int ReceiveData[2][ReceiveDataLeng]; //传感器类型；数据瀑布流
QVector<int> vectorA;
QVector<int> vectorB;
int TXTmp[7];
long RefreshCount=0;
int CommaCount=0;
int ThrowPack=0;
bool KeepInertia=true; //数据包丢失时图表依旧刷新，但是继承上一次的数据，有利于保持图表精度，该选项无需人为调整!!!
MainWindow::MainWindow(QWidget *parent) :
  QMainWindow(parent),
  ui(new Ui::MainWindow)
{

  Sleep(1500);//给启动画面延迟后打开主窗口

  ui->setupUi(this);
  setWindowTitle(tr("强基创发 Stm32光电门实验 V1.0"));
  setWindowIcon(QIcon("./img/logo.png"));
  //限制窗体大小，防止看到不该看到的东西，如DEBUG留下的控制窗体
  setWindowFlags(windowFlags()& ~Qt::WindowMaximizeButtonHint);
  setFixedSize(this->width(), this->height());
  on_pushButton_clicked();
  //初始化变量
  Timeout_redraw_timer=new QTimer(this);
  Record_Wave_timer=new QTimer(this);
  //设置timer超时事件与处理函数连接起来
  connect(Timeout_redraw_timer,SIGNAL(timeout()),this,SLOT(Timeout_redraw()));
  connect(Record_Wave_timer,SIGNAL(timeout()),this,SLOT(Record_Wave()));
}

MainWindow::~MainWindow()
{
  delete ui;
}

bool CheckDataIntegrity() {
    return TXTmp[3]==TXTmp[0]+TXTmp[1]+TXTmp[2]+TXTmp[4]+TXTmp[5]+TXTmp[6];
}

void ReceiveDataRoll() {
    if (vectorA.size()>=ReceiveDataLeng) {
        //因为A和B两个容器是同时进行操作的，长度都是一致的，判断其中一个足够了
        vectorA.remove(0,1);
        vectorB.remove(0,1);
    }
    //验证校验码确保数据完整性，不完整则丢包
    if (CheckDataIntegrity()) {
        vectorA<<TXTmp[1];
        vectorB<<TXTmp[2];
    }else if (KeepInertia&&vectorA.size()>0) {
        //检测到数据不完整，但由于“保持惯性”已开启，自动继承最近一次接收到的有效数据
        qDebug()<<"容器长度"<<vectorA.size();
        vectorA<<vectorA.at(vectorA.size()-2);
        vectorB<<vectorB.at(vectorA.size()-2);
    }
}

void MainWindow::Timeout_redraw(){

    update();
    //repaint();
}

void MainWindow::Record_Wave(){
    if (CommaCount>=3) ReceiveDataRoll();
}
void MainWindow::paintEvent(QPaintEvent *)
{

    QPainter painter(this);
    QColor green(0,255,87);
    QColor red(255,53,0);
    QColor yellow(255,210,160);
    QPen penG(green);
    QPen penR(red);
    QPen penY(yellow);
    QBrush brush(QColor(17, 43, 56, 255)); //决定图表背景框的颜色
    painter.setBrush(brush);
    painter.setRenderHints(QPainter::Antialiasing); //进行平滑抗锯齿
    painter.translate(Graphics_Frame_X, Graphics_Frame_Y); //移动坐标原点
    painter.drawRect(0, 0, ReceiveDataLeng*2, 256); //框
    //绘制刻度线
    painter.setPen(penY);
    for (int y=60;y<256;y+=10)
        for (int x=0;x<vectorA.size()*2;x+=10)
            painter.drawPoint(x, y);
    //绘制波形图
    for (int i=0;i<vectorA.size()-1;i++) {
        painter.setPen(penG);
        painter.drawLine(QPointF(i*2, vectorA.at(i)/16), QPointF((i+1)*2, vectorA.at(i+1)/16));
        painter.setPen(penR);
        painter.drawLine(QPointF(i*2, vectorB.at(i)/16), QPointF((i+1)*2, vectorB.at(i+1)/16));
    }
    //QApplication::processEvents();

}




void MainWindow::on_OpenSerialButton_clicked()
{
  if (ui->OpenSerialButton->text() == tr("打开串口"))
  {
    serial = new QSerialPort;
    //设置串口名
    serial->setPortName(ui->PortBox->currentText());
    //打开串口
    serial->open(QIODevice::ReadWrite);
    //设置波特率
    serial->setBaudRate(QSerialPort::Baud115200);//设置波特率为11520
    serial->setDataBits(QSerialPort::Data8);//设置数据位8
    serial->setParity(QSerialPort::NoParity);
    serial->setStopBits(QSerialPort::OneStop);//停止位设置为1
    //设置流控制
    serial->setFlowControl(QSerialPort::NoFlowControl);//设置为无流控制

    //关闭设置菜单使能
    ui->PortBox->setEnabled(false);
    ui->BaudBox->setEnabled(false);
    ui->OpenSerialButton->setText(tr("关闭串口"));
    //连接信号槽
    QObject::connect(serial, &QSerialPort::readyRead, this, &MainWindow::ReadData);
    //启动定时器
    Timeout_redraw_timer->start(66); //限制画面帧率 节省资源 FPS=15
    Record_Wave_timer->start(1);
  }
  else
  {
    //关闭串口
    serial->clear();
    serial->close();
    serial->deleteLater();

    //恢复设置使能
    ui->PortBox->setEnabled(true);
    ui->BaudBox->setEnabled(true);
    ui->OpenSerialButton->setText(tr("打开串口"));
    //关闭定时器
    Timeout_redraw_timer->stop();
    Record_Wave_timer->stop();
  }
}




//读取接收到的信息
void MainWindow::ReadData()
{
  QByteArray buf;
  buf = serial->readAll();
  QString str,tmp;
  CommaCount=0;
  if (!buf.isEmpty())
  {
    str = tr(buf);
    //开始读取以逗号分割的字符串
    for (int i=0;i<str.length();i++) {
        if (str[i]==",") {
            if (tmp.toInt()>=0&&CommaCount<7) {
                if (CommaCount==0&&tmp.toInt()<800) {
                    break;
                }else TXTmp[CommaCount]=tmp.toInt();
            }else break;
            tmp="";
            CommaCount++;
           /* if (CommaCount>=3) {
                if (ThrowPack>50) {  //防止采样速率过快，选择性进行丢包
                ReceiveDataRoll();
                ThrowPack=0;
                }
                ThrowPack++;
            }*/
        }else tmp+=str[i];
    }
    //ui->label_5->setText(tmp);
    //ui->textEdit->append(str);
    if (CheckDataIntegrity()) {
    ui->label_5->setText(QString::number(TXTmp[0], 10).toUpper());
    ui->label_7->setText(QString::number(TXTmp[1], 10).toUpper());
    ui->label_8->setText(QString::number(TXTmp[2], 10).toUpper());
    ui->label_12->setText(QString::number(TXTmp[3], 10).toUpper());
    ui->label_20->setText(QString::number(TXTmp[4], 10).toUpper());
    ui->label_21->setText(QString::number(TXTmp[5], 10).toUpper());
    ui->label_22->setText(QString::number(TXTmp[6], 10).toUpper());
    }
      //ui->textEdit->clear();
  }

  buf.clear();
}


void MainWindow::on_pushButton_clicked()
{
  //查找可用的串口
  ui->PortBox->clear();
  foreach (const QSerialPortInfo &info, QSerialPortInfo::availablePorts())
  {
    QSerialPort serial;
    serial.setPort(info);
    if (serial.open(QIODevice::ReadWrite))
    {
      ui->PortBox->addItem(serial.portName());
      serial.close();
    }
  }
  //设置波特率下拉菜单默认显示第0项
  ui->BaudBox->setCurrentIndex(4);
}


//计算加速度
void MainWindow::on_pushButton_2_clicked()
{
    QString t1 = ui->label_20->text();
    QString t2 = ui->label_21->text();
    QString t3 = ui->label_22->text();
    QString s2 = ui->S2->text();

    //触发彩蛋 如果输入的挡光片长度为2020就会打开项目链接
    //if (s2.toInt()==2020) QDesktopServices::openUrl(QUrl(QLatin1String("https://github.com/createskyblue/PhotoelectricDoor")));
    if (s2.toInt()==2020) QDesktopServices::openUrl(QUrl(QLatin1String("https://gitee.com/createskyblue/PhotoelectricDoor")));
    double v1,v2;
    v1=s2.toDouble()*10.0/t1.toDouble();
    v2=s2.toDouble()*10.0/t2.toDouble();
    double ObjectAcceleration;
    ObjectAcceleration=double(v2-v1)*1000/(t3.toDouble());
    qDebug()<<ObjectAcceleration;
    ui->OjA->setText(QString::number(ObjectAcceleration, '.', 7));
}

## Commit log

2020-07-11 第一个版本
    赠予彭中物理科组的光电门实验教具下位机驱动程序
2020-07-21 修复bug
    修复bug
    增加串口通讯内容，实现与上位机进行单项通讯
2020-07-21 增添上位机程序
    使用上位机程序通过串口与下位机通讯可进行可视化数据分析以及更好地实现教学演示
    [实验数据分析.xlsx]
2020-07-21 更新README
    更新实验步骤
    统一实验数据分析表格计算参考系
    [实验数据分析.xlsx]
2020-07-21 修复README图片路径错误
2020-07-21 更新操作说明
    操作说明
    接线图
    材料清单
    [stm32.fzz]
2020-07-31 更新动态光适应机制
    1.相比于上一个版本，该版本无需因为光照条件的改变从而为了准确性被迫重启
    2.上次更新：修复传感器历史数据列表没有正确移动的问题
2020-08-01 UI更新
    1.更新UI界面
    2.修复数据区域数组溢出的问题：扩增数组
    3.增加测试模式，可以通过在启动动画结束前遮挡光敏电阻从而进入模式选择画面，按照提示继续遮挡即可进入测试模式
    4.测试模式中可以测试两个传感器的灵敏度，用于组装实验教具后验证可用性
    5.增加启动动画替代原本的随机静态画面
    [PhotoelectricDoor.ino]

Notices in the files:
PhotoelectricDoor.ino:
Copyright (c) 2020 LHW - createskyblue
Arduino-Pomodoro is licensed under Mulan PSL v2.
